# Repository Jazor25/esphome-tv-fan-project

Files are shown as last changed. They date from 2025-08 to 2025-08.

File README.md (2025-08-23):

# ESPHome TV Fan Project

This project demonstrates how to build a thermostat-controlled fan system for cooling gaming consoles, media players, or other hardware housed in enclosed cabinets. It includes a custom 3D-printed case that perfectly accommodates all components.

The system controls 2 fans independently based on temperature readings from 2 separate DHT22 sensors, and can easily be extended to support additional fans and sensors.

This solution integrates natively with Home Assistant via ESPHome while also operating autonomously, controlling fans based on cabinet temperature without external dependencies.

# Motivation

I wanted to create a clean TV/media setup in our living room with minimal visible devices on or around the TV cabinet. However, running hardware in closed cabinets without proper cooling leads to overheating issues, so I needed an effective cooling solution. I had previously built a similar system using an Arduino Uno three years ago, but it was no longer functioning reliably and lacked Home Assistant integration.

This project draws inspiration from the excellent work of [patrickcollins12 on GitHub](https://github.com/patrickcollins12/esphome-fan-controller). I developed my own version for several specific reasons:

* I only had 3-pin fans from a previous setup (no PWM control available)
* I wanted a transistor-controlled switching solution for reliable fan operation (PWM signals aren't always dependable for complete fan shutdown)
* My PlayStation 5 generates significant heat quickly, requiring fans to run at 100% capacity. Since I use ultra-quiet Noctua fans, speed reduction isn't necessary from a noise perspective. 

## Visuals
*(Additional images are available in the /img folder)*

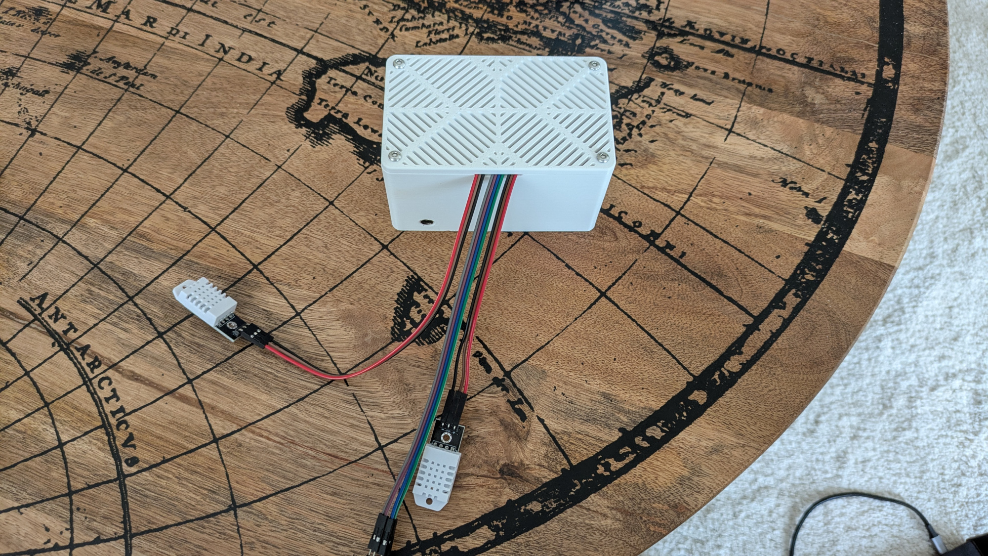
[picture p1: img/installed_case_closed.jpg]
Installed Case (Closed)

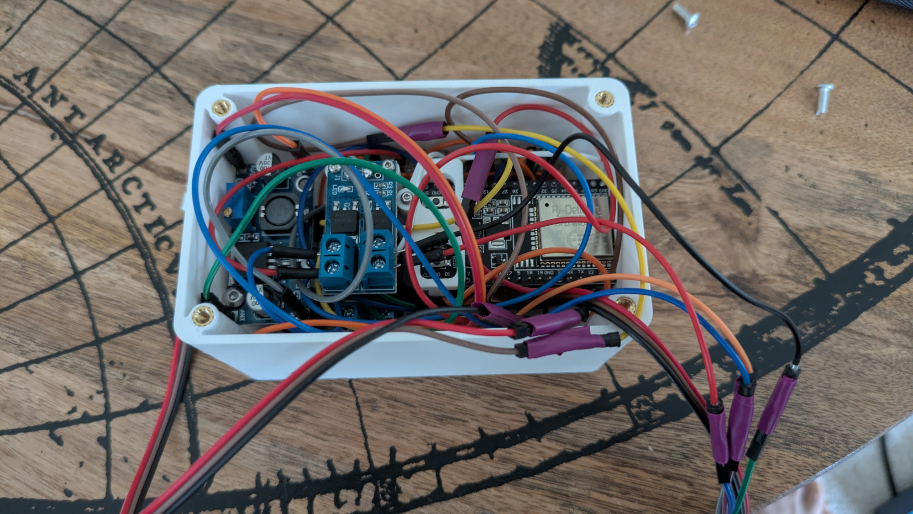
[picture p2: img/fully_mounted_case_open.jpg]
Mounted Case (Open)

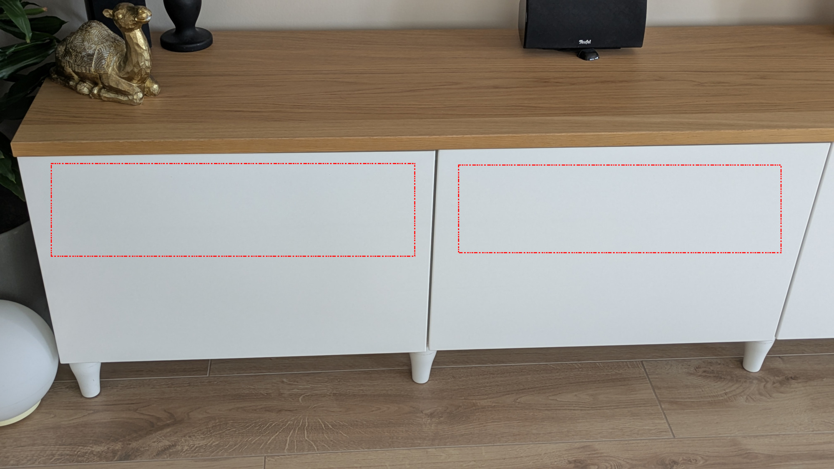
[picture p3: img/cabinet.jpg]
cabinet

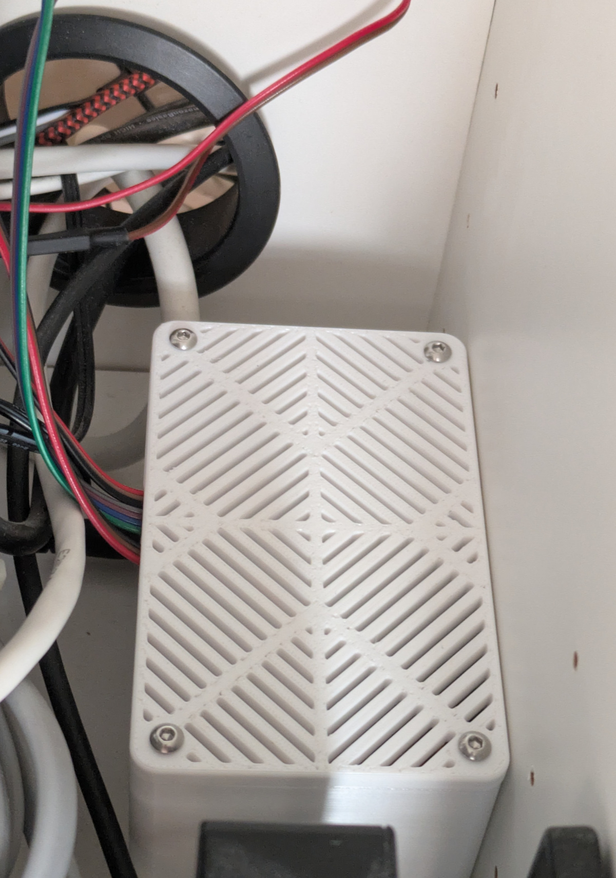
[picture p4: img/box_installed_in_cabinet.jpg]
Installed Case in cabinet

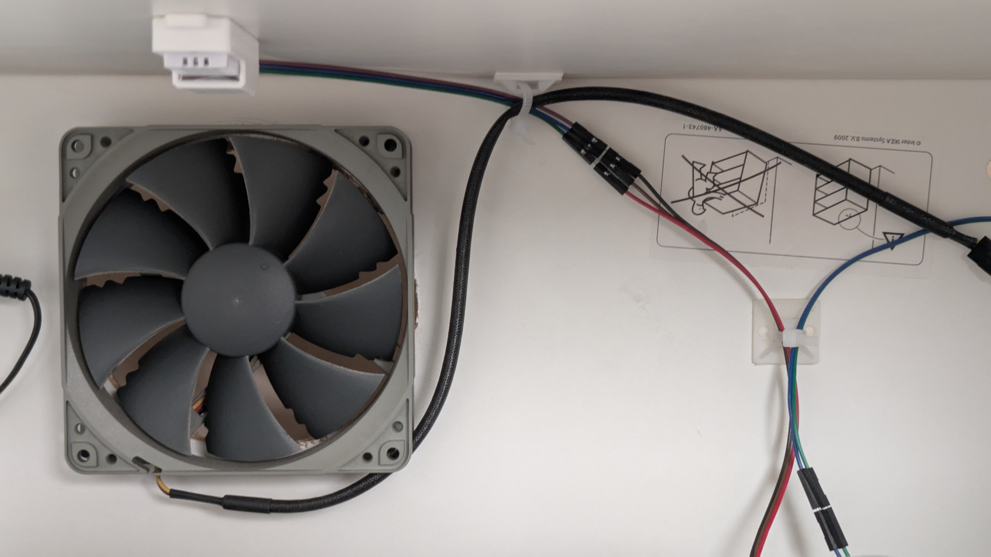
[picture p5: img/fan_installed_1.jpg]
Installed Fan 1

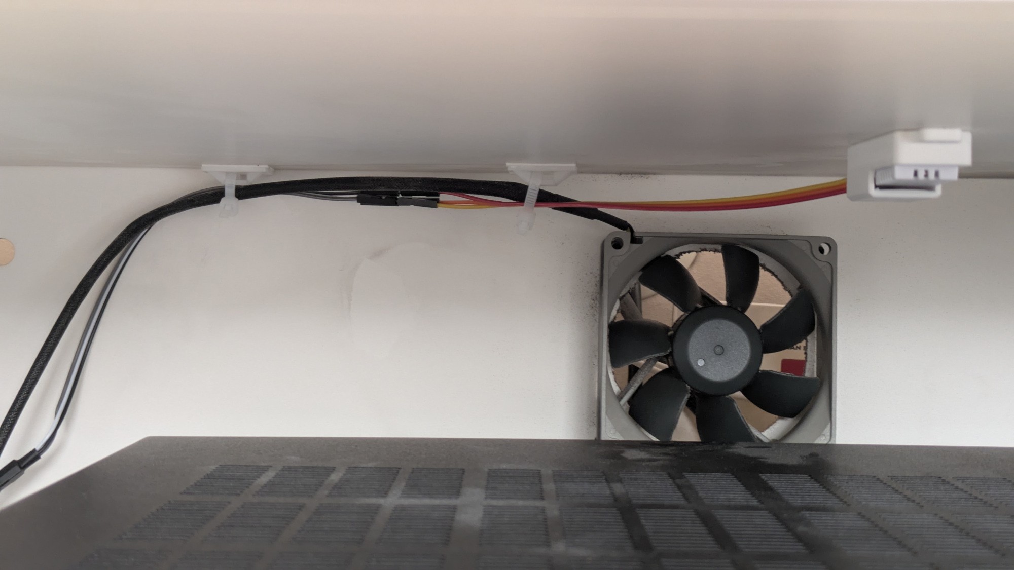
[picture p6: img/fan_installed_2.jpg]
Installed Fan 2

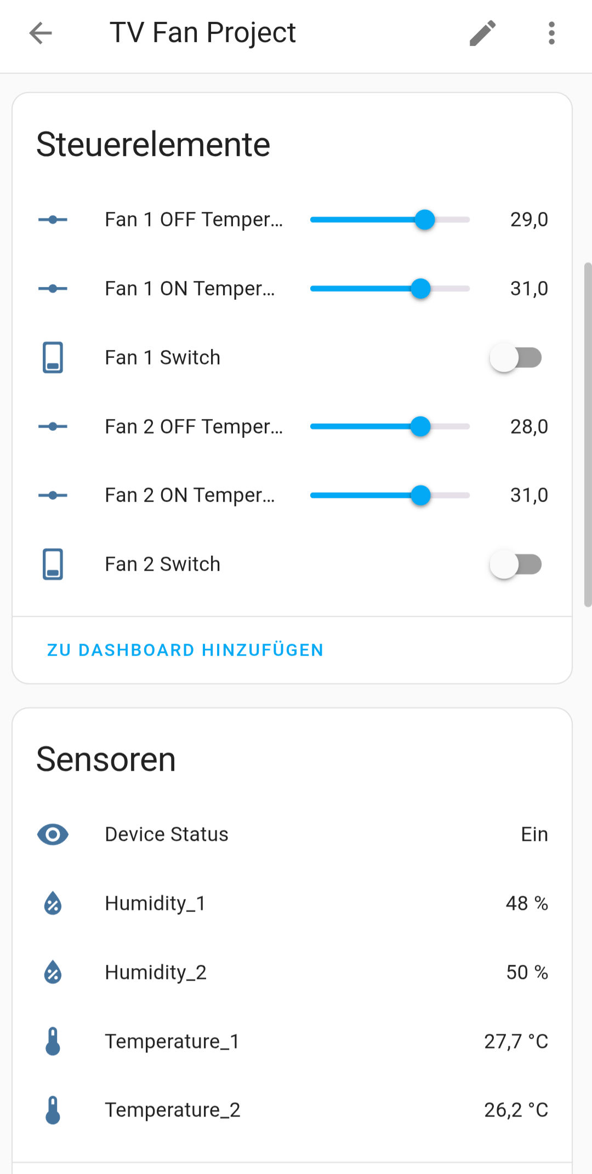
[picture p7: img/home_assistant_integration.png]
Home Assistant Integration

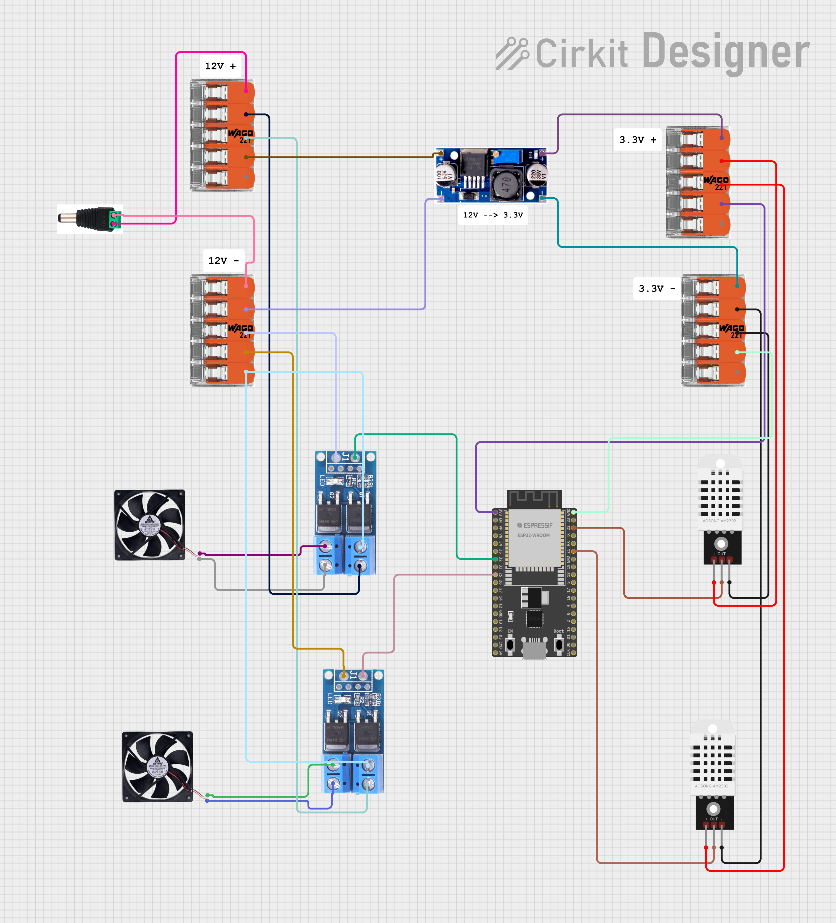
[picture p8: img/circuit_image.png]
Circuit Wiring


## Hardware Components

* ESP32 Development Board (Used: ESP32 V4 with CP2102, AZDelivery)
* 2× DC 5V-36V 400W FET Trigger Switch Boards
* 1× LM2596s Step-Down Voltage Regulator (24V/12V/5V/3V Buck Converter)
* 2x DHT22 Temperature/Humidity Sensors
* 2× 12V PC Fans (2-pin configuration)
* 12V 1-2A Power Supply
* 12V Male-to-Female Power Adapter
* Jumper cables
* 4× WAGO 221-415, COMPACT Splicing Connector, 5-pole (Optional, but fit well into the 3D-printed case) 

## Wiring & Pin Assignments

### GPIO Pin Usage
| GPIO Pin | Component | Description |
|---|---|---|
| GPIO22 | DHT22 #1  | Temperature/Humidity Sensor 1 |
| GPIO21 | DHT22 #2  | Temperature/Humidity Sensor 2 |
| GPIO32 | FET Board #1 | Fan 1 Control Signal |
| GPIO25 | FET Board #2 | Fan 2 Control Signal |

### Wiring Diagrams
- **[Complete Wiring Guide](docs/wiring_diagrams.md)** - Detailed connection tables, safety notes, and troubleshooting
- **[Visual Schematic](docs/detailed_schematic.txt)** - ASCII art diagram showing component connections
- **[Cable Assignments](img/cable_assignments.png)** - Physical cable reference

### Key Connections
- **Power**: 12V supply → LM2596s (configured to 3.3V) → ESP32 VIN
- **Sensors**: DHT22 data pins connected to GPIO22/21, powered by ESP32 3.3V
- **Fan Control**: GPIO32/25 → FET board signal pins
- **Ground**: Common ground connection for all components

## Features

- **Independent Control**: Each fan operates based on its dedicated temperature sensor
- **Configurable Thresholds**: Customize ON/OFF temperatures through Home Assistant
- **Hysteresis Control**: Prevents rapid fan cycling for stable operation
- **Web Interface**: Built-in web server for monitoring and control
- **Home Assistant Integration**: Full API integration with encryption support

## 3D Printed Case Hardware

* 5× Ruthex M3 Threaded Inserts
* 5× M3 Screws
* 7× Ruthex M2 Threaded Inserts  
* 7× M2 Screws

## Assembly Guidelines

* **Voltage Regulation**: The buck converter must be precisely adjusted to 3.3V to prevent damage to the ESP32 and connected modules. Connect 12V to the input pins, attach a multimeter (set to voltage mode) to the output pins, and carefully adjust the potentiometer with a screwdriver until the multimeter reads exactly 3.3V.

* **Compact Design**: The 3D case is designed for minimal size, which limits assembly flexibility. When soldering pins to components, ensure one of the FET boards has pins soldered "upside down" - otherwise, the case won't close properly. Refer to the images in the img folder if uncertain about component orientation. On the other hand, you avoid these issues if you use flexible soldering cables instead of jumper cables.

* **Safety Precautions**: Prevent bare 12V and 3.3V wire ends from touching each other, as this can cause immediate component failure. Use heat shrink tubing or electrical tape to insulate exposed connections, especially where jumper cables might accidentally contact each other and create short circuits. 

## License

This project is published under [CC BY-NC-SA 4.0](https://creativecommons.org/licenses/by-nc-sa/4.0/).

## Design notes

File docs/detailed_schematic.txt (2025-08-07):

```
ESP32 Fan Control System - Detailed Wiring Schematic
=====================================================

                    12V 1-2A Power Supply
                    ┌─────────────────────┐
                    │        +12V    GND  │
                    └──────────┬───────┬──┘
                               │       │
                    ┌──────────┴───────┴────────────────────────┐
                    │                                           │
                    │         Power Distribution                │
                    │                                           │
         ┌──────────┴─────┐    ┌─────────────────┐    ┌────────┴────────┐
         │                │    │                 │    │                 │
         │   LM2596s      │    │   FET Board #1  │    │   FET Board #2  │
         │ Buck Converter │    │   (GPIO32)      │    │   (GPIO25)      │
         │                │    │                 │    │                 │
         │ IN+  ←─ 12V    │    │ VCC ←─ 12V      │    │ VCC ←─ 12V      │
         │ IN-  ←─ GND    │    │ GND ←─ GND      │    │ GND ←─ GND      │
         │ OUT+ ──→ 3.3V  │    │ SIG ←─ ESP32    │    │ SIG ←─ ESP32    │
         │ OUT- ──→ GND   │    │ DC+ ──→ Fan #1+ │    │ DC+ ──→ Fan #2+ │
         └────────┬───────┘    │ DC- ──→ Fan #1- │    │ DC- ──→ Fan #2- │
                  │            └─────────┬───────┘    └─────────┬───────┘
                  │                      │                      │
                  │            ┌─────────┴───────┐    ┌─────────┴───────┐
                  │            │     Fan #1      │    │     Fan #2      │
                  │            │   (12V RPM)     │    │   (12V RPM)     │
                  │            │  Red(+) Black(-)│    │  Red(+) Black(-)│
                  │            └─────────────────┘    └─────────────────┘
                  │
            ┌─────┴─────────────────────────────────────────────────────┐
            │                    ESP32 V4                                │
            │                  (CP2102)                                  │
            │                                                            │
            │  VIN ←─ 3.3V (from LM2596s)                                │
            │  GND ←─ Common Ground                                      │
            │                                                            │
            │  GPIO22 ──→ DHT22 #1 Data   GPIO21 ──→ DHT22 #2 Data     │
            │  GPIO32 ──→ FET Board #1    GPIO25 ──→ FET Board #2       │
            │  3.3V   ──→ DHT22 Power (both sensors)                    │
            │                                                            │
            └──────────────┬─────────────────────┬─────────────────────┘
                           │                     │
                ┌──────────┴───────┐  ┌──────────┴───────┐
                │    DHT22 #1      │  │    DHT22 #2      │
                │ (Temperature &   │  │ (Temperature &   │
                │  Humidity)       │  │  Humidity)       │
                │                  │  │                  │
                │ 1. VCC ←─ 3.3V   │  │ 1. VCC ←─ 3.3V   │
                │ 2. Data ─→ GPIO22│  │ 2. Data ─→ GPIO21│
                │ 3. NC            │  │ 3. NC            │
                │ 4. GND ←─ GND    │  │ 4. GND ←─ GND    │
                │                  │  │                  │
                │ Note: Add 10kΩ   │  │ Note: Add 10kΩ   │
                │ pull-up resistor │  │ pull-up resistor │
                │ VCC to Data      │  │ VCC to Data      │
                └──────────────────┘  └──────────────────┘

Ground Distribution:
==================
                            Common Ground Bus
    ┌─────────────────────────────────────────────────────────────┐
    │                                                             │
    ├─ 12V Power Supply (-)                                       │
    ├─ LM2596s (IN-, OUT-)                                        │
    ├─ ESP32 (GND)                                                │
    ├─ DHT22 #1 (Pin 4)                                           │
    ├─ DHT22 #2 (Pin 4)                                           │
    ├─ FET Board #1 (GND)                                         │
    └─ FET Board #2 (GND)                                         │

Control Logic:
=============
Temperature Sensor 1 (GPIO22) → Controls → Fan 1 (GPIO32)
Temperature Sensor 2 (GPIO21) → Controls → Fan 2 (GPIO25)

Default Settings:
- Fan ON Temperature: 31.0°C
- Fan OFF Temperature: 29.0°C (Fan 1), 28.0°C (Fan 2)
- Check Interval: 10 seconds
- Sensor Update: 20 seconds

Signal Flow:
===========
DHT22 → ESP32 → Temperature Reading → Logic → GPIO Output → FET Board → Fan Control

Power Flow:
==========
12V Supply → LM2596s → 3.3V → ESP32
12V Supply → FET Boards → Fans (when triggered)
ESP32 3.3V → DHT22 Sensors
```

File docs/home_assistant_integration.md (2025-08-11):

# Adding ESPHome Fan Project to Home Assistant

## Method 1: ESPHome Add-on (Recommended)

### Prerequisites
- Home Assistant with Supervisor (Home Assistant OS or Supervised)
- ESPHome Add-on installed

### Step-by-Step Instructions

#### 1. Install ESPHome Add-on
1. Go to **Settings** → **Add-ons** → **Add-on Store**
2. Search for "ESPHome" 
3. Click **Install** on the official ESPHome add-on
4. Start the add-on and enable **Start on boot**

#### 2. Add Your Device
1. Open ESPHome add-on web UI
2. Click **+ NEW DEVICE**
3. Choose **Continue** 
4. Enter device details:
   - **Name**: `tv-fan-project`
   - **Device Type**: Choose ESP32
5. Skip the wireless credentials (we'll use existing config)

#### 3. Upload Your Configuration
1. In ESPHome dashboard, click **EDIT** on your new device
2. Replace the generated content with your `tv-fan-project.yaml` content
3. Create a `secrets.yaml` file with:
   ```yaml
   wifi_ssid: "Your_WiFi_Name"
   wifi_password: "Your_WiFi_Password"
   ```
4. Click **SAVE**

#### 4. Compile and Flash
1. Click **INSTALL** 
2. Choose **Wirelessly** (if device is already flashed) or **Plug into this computer**
3. Wait for compilation and upload

#### 5. Auto-Discovery in Home Assistant
- Once online, the device should appear in **Settings** → **Devices & Services**
- Look for "ESPHome" integration with your device
- Click **CONFIGURE** if prompted

## Method 2: Standalone ESPHome Installation

### If you're running ESPHome separately (not as HA add-on):

#### 1. Ensure API Configuration
Your configuration already has the API enabled:
```yaml
api:
  encryption:
    key: "YOUR_API_ENCRYPTION_KEY_HERE"
```

#### 2. Manual Integration
1. Go to **Settings** → **Devices & Services**
2. Click **+ ADD INTEGRATION**
3. Search for "ESPHome"
4. Enter your ESP32's IP address
5. Enter the encryption key from your ESPHome config

## Method 3: MQTT Integration (Alternative)

### If you prefer MQTT, add this to your ESPHome config:

```yaml
mqtt:
  broker: your_mqtt_broker_ip
  username: !secret mqtt_username
  password: !secret mqtt_password
  discovery: true
  discovery_retain: false
  topic_prefix: esphome/tv_fan_project
```

## Device Configuration for Better HA Integration

### Add Device Information
Add this to your ESPHome configuration for better device identification:

```yaml
esphome:
  name: tv-fan-project
  friendly_name: TV Fan Project
  comment: "Dual fan temperature control system"
  project:
    name: "custom.tv_fan_control"
    version: "1.0"

# Device information for Home Assistant
device_info:
  manufacturer: "Custom Build"
  model: "ESP32 Fan Controller"
  sw_version: "1.0"
```

## Expected Home Assistant Entities

After successful integration, you'll see these entities:

### 🌡️ **Climate Sensors**
- `sensor.tv_fan_project_temperature_1`
- `sensor.tv_fan_project_temperature_2` 
- `sensor.tv_fan_project_humidity_1`
- `sensor.tv_fan_project_humidity_2`

### 🔌 **Switches & Controls**
- `switch.tv_fan_project_fan_1_switch`
- `switch.tv_fan_project_fan_2_switch`
- `number.tv_fan_project_fan_on_temperature`
- `number.tv_fan_project_fan_on_temperature_2`
- `number.tv_fan_project_fan_off_temperature_1`
- `number.tv_fan_project_fan_off_temperature`

### 📊 **System Monitoring**
- `sensor.tv_fan_project_uptime`
- `sensor.tv_fan_project_wifi_signal`
- `text_sensor.tv_fan_project_fan_control_status`

### 🏠 **Device Status**
- `binary_sensor.tv_fan_project_status` (online/offline)

## Creating a Dashboard Card

### Example Lovelace Card Configuration:

```yaml
type: entities
title: TV Fan Control System
entities:
  - entity: text_sensor.tv_fan_project_fan_control_status
    name: System Status
  - type: divider
  - entity: sensor.tv_fan_project_temperature_1
    name: Temperature Zone 1
  - entity: sensor.tv_fan_project_temperature_2
    name: Temperature Zone 2
  - type: divider
  - entity: switch.tv_fan_project_fan_1_switch
    name: Fan 1 Manual Control
  - entity: switch.tv_fan_project_fan_2_switch
    name: Fan 2 Manual Control
  - type: divider
  - entity: number.tv_fan_project_fan_on_temperature
    name: Fan 1 ON Temp
  - entity: number.tv_fan_project_fan_off_temperature_1
    name: Fan 1 OFF Temp
  - entity: number.tv_fan_project_fan_on_temperature_2
    name: Fan 2 ON Temp
  - entity: number.tv_fan_project_fan_off_temperature
    name: Fan 2 OFF Temp
```

## Automation Example

### Create automations in Home Assistant:

```yaml
# Example: Notification when fan turns on
automation:
  - alias: "Fan System Alert"
    trigger:
      - platform: state
        entity_id: switch.tv_fan_project_fan_1_switch
        to: 'on'
      - platform: state
        entity_id: switch.tv_fan_project_fan_2_switch
        to: 'on'
    action:
      - service: notify.mobile_app_your_phone
        data:
          message: "Fan {{ trigger.entity_id.split('.')[1] }} activated due to high temperature"
```

## Troubleshooting

### Device Not Appearing
1. **Check Network**: Ensure ESP32 and HA are on same network
2. **Verify API**: Confirm API encryption key matches
3. **Check Logs**: Look in HA logs for connection errors
4. **Manual Add**: Try adding via IP address manually

### Connection Issues
1. **Firewall**: Ensure port 6053 is open for ESPHome API
2. **WiFi Signal**: Check `sensor.tv_fan_project_wifi_signal` strength
3. **Restart**: Reboot both ESP32 and Home Assistant

### Entity Names
- Entity names will be prefixed with your device name
- Use **Settings** → **Devices & Services** → **ESPHome** → your device to customize entity names

## Advanced Features

### Group Configuration
Create groups for easier management:

```yaml
# In configuration.yaml
group:
  fan_control_system:
    name: "TV Fan Control System"
    entities:
      - switch.tv_fan_project_fan_1_switch
      - switch.tv_fan_project_fan_2_switch
      - sensor.tv_fan_project_temperature_1
      - sensor.tv_fan_project_temperature_2
```

### Template Sensors
Create calculated sensors:

```yaml
# Average temperature sensor
template:
  - sensor:
      - name: "Average Room Temperature"
        unit_of_measurement: "°C"
        state: >
          {{ ((states('sensor.tv_fan_project_temperature_1') | float + 
               states('sensor.tv_fan_project_temperature_2') | float) / 2) | round(1) }}
```

Once you follow these steps, your ESPHome fan control system will be fully integrated into Home Assistant with all entities available for monitoring, control, and automation!

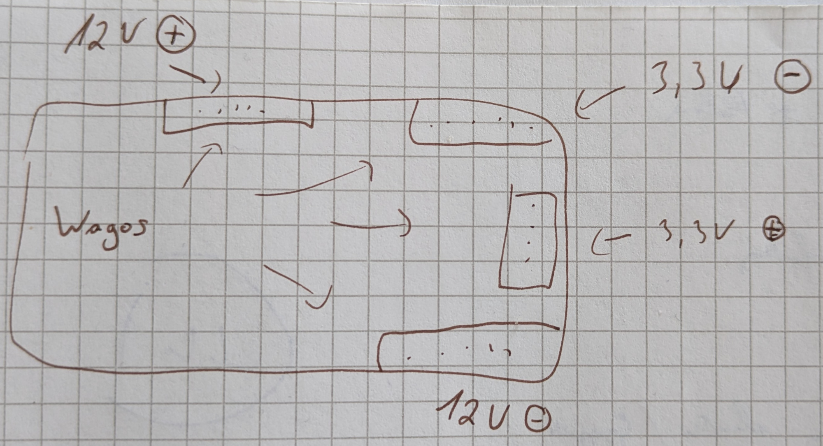
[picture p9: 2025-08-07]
img/wago_box_placement.jpg

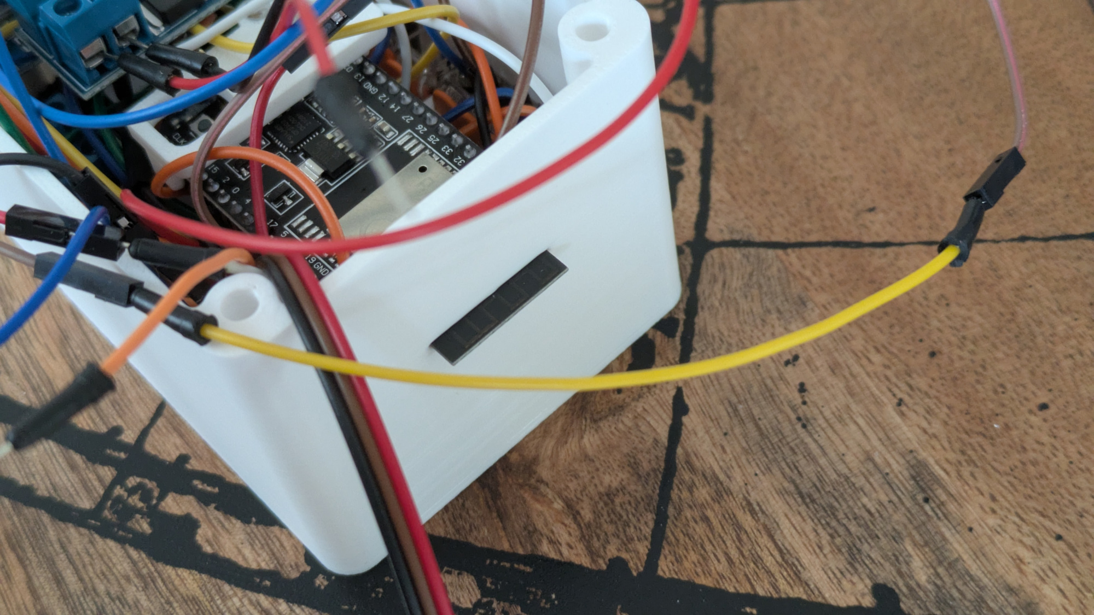
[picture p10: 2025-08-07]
img/esp32_antenna.jpg

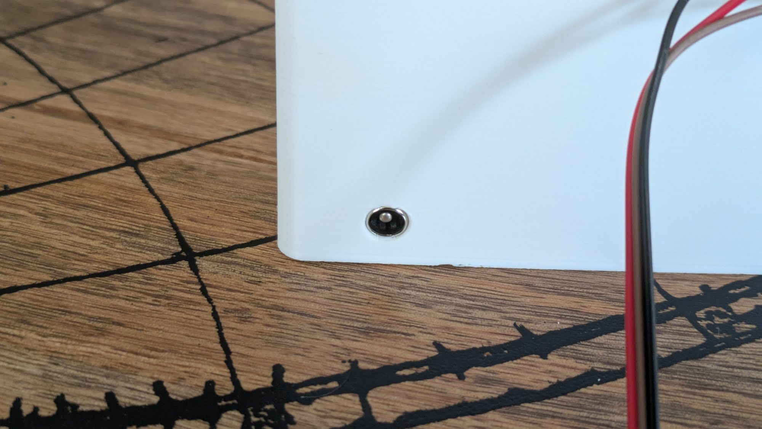
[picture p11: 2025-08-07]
img/12v_power_plug_female.jpg

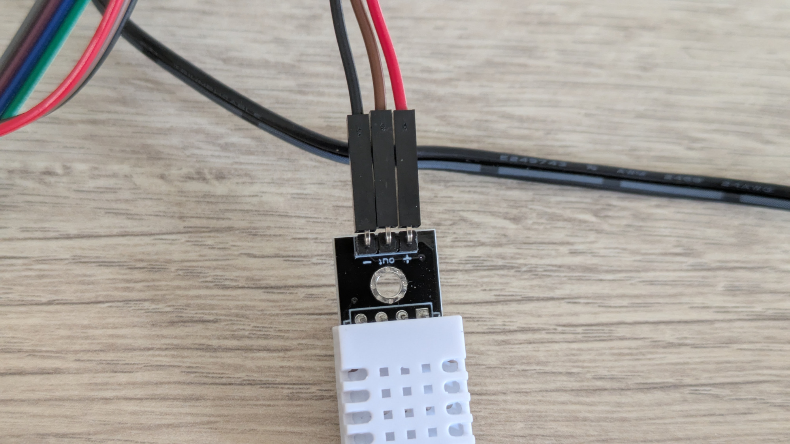
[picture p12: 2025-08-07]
img/DHT22_pin_assignment.jpg

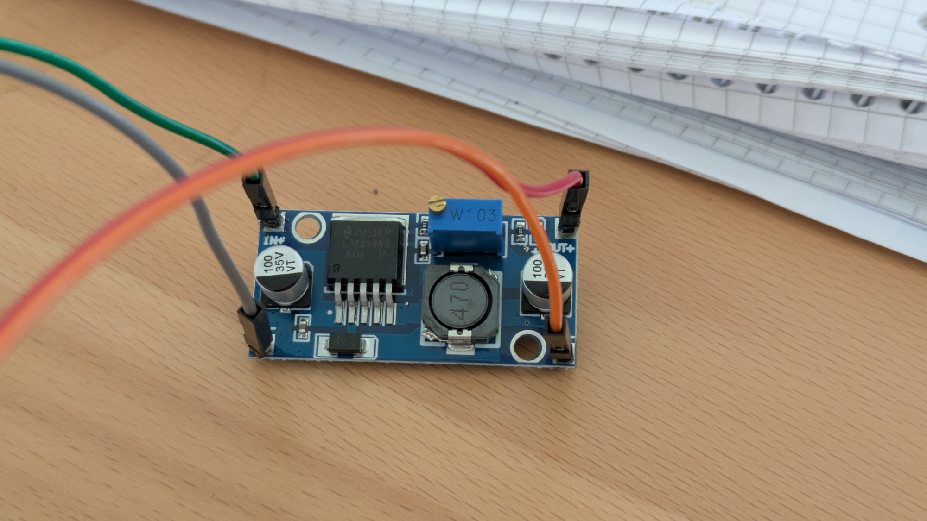
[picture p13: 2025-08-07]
img/LM2596s_buck_transformer.jpg

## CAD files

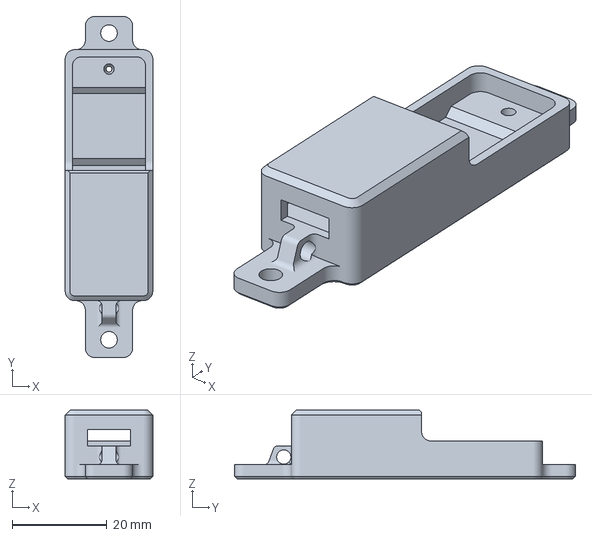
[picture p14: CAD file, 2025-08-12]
3d-print-files/DHT_Gehäuse.3mf
18.5 x 72.0 x 14.5 mm

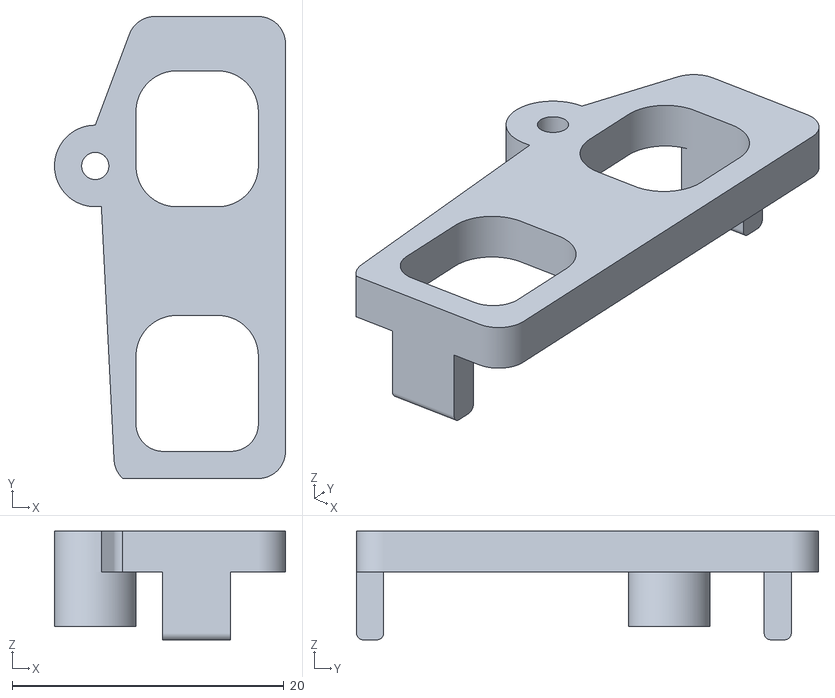
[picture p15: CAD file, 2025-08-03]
3d-print-files/box-esp32-holder.stl
17.0 x 34.0 x 8.00

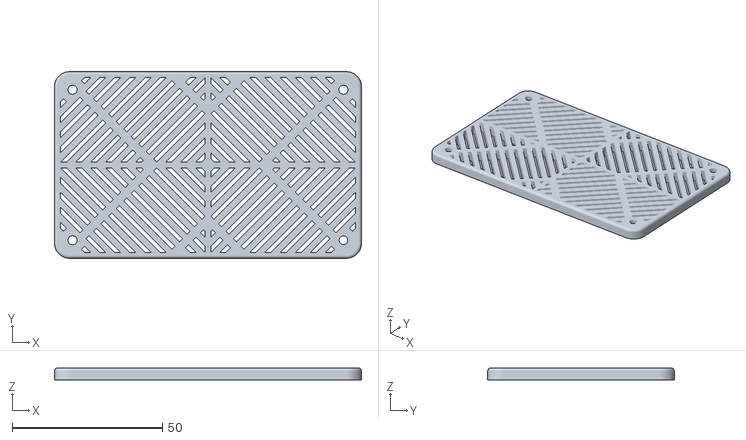
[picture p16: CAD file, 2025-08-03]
3d-print-files/box-cover-v2.stl
102.0 x 62.0 x 4.00

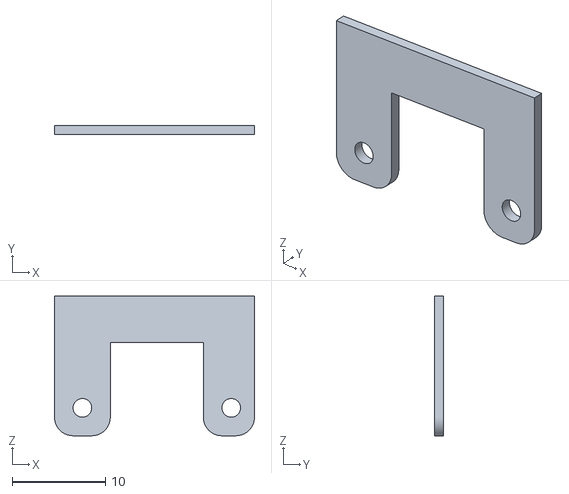
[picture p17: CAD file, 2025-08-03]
3d-print-files/box-powerplug-holder.stl
21.5 x 1.00 x 15.0

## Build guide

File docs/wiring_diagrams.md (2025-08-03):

# Wiring Diagrams - ESP Home Fan Project

## Pin Assignments Summary

### ESP32 GPIO Pin Usage
| GPIO Pin | Component | Description |
|---|---|---|
| GPIO22 | DHT22 #1  | Temperature/Humidity Sensor 1 |
| GPIO21 | DHT22 #2  | Temperature/Humidity Sensor 2 |
| GPIO32 | FET Board #1 | Fan 1 Control Signal |
| GPIO25 | FET Board #2 | Fan 2 Control Signal |
| 3.3V | DHT22 VCC | Power for both DHT22 sensors |
| GND | DHT22 GND | Ground for both DHT22 sensors |

## Main Wiring Diagram

```
                           ┌─────────────────┐
                           │     ESP32       │
                           │   (ESP32 V4)    │
                           │                 │
┌─────────────┐           │  GPIO22  ────── │ ──── DHT22 #1 Data
│             │           │  GPIO21  ────── │ ──── DHT22 #2 Data
│  12V Power  │           │  GPIO32  ────── │ ──── FET Board #1 Signal
│   Supply    │           │  GPIO25  ────── │ ──── FET Board #2 Signal
│             │           │                 │
│   +12V ─────┼───────────│  VIN     ────── │ ──── 12V --> 3.3V Input (via Buck Converter)
│    GND ─────┼───────────│  GND     ────── │ ──── Common Ground
└─────────────┘           │  3.3V    ────── │ ──── DHT22 VCC (both sensors)
                           └─────────────────┘
                                    │
                                    │
                           ┌─────────────────┐
                           │  LM2596s Buck   │
                           │   Converter     │
                           │   (24V→5V/3V)   │
                           │                 │
                           │  IN+  ←─ 12V    │
                           │  IN-  ←─ GND    │
                           │  OUT+ ──→ 3.3V  │ ──── To ESP32 VIN
                           │  OUT- ──→ GND   │ ──── Common Ground
                           └─────────────────┘
```

## DHT22 Sensors Wiring

```
DHT22 Sensor #1                    DHT22 Sensor #2
┌─────────────┐                    ┌─────────────┐
│      ┌─┐    │                    │      ┌─┐    │
│   1 ─┤ |    │                    │   1 ─┤ |    │
│   2 ─┤ ├─ 3 │                    │   2 ─┤ ├─ 3 │
│      └─┘    │                    │      └─┘    │
└─────────────┘                    └─────────────┘
Pin 1: VCC (3.3V)                  Pin 1: VCC (3.3V)
Pin 2: Data → GPIO22               Pin 2: Data → GPIO21
Pin 3: GND                         Pin 3: GND

```

## FET Switch Board Connections

```
FET Board #1                       FET Board #2
┌─────────────────┐                ┌─────────────────┐
│  DC+ ←─ Fan 1 + │                │  DC+ ←─ Fan 2 + │
│  DC- ←─ Fan 1 - │                │  DC- ←─ Fan 2 - │
│                 │                │                 │
│  VCC ←─ 12V     │                │  VCC ←─ 12V     │
│  GND ←─ GND     │                │  GND ←─ GND     │
│  SIG ←─ GPIO32  │                │  SIG ←─ GPIO25  │
└─────────────────┘                └─────────────────┘
       │                                  │
       │                                  │
┌─────────────┐                    ┌─────────────┐
│   Fan #1    │                    │   Fan #2    │
│  (12V RPM)  │                    │  (12V RPM)  │
│             │                    │             │
│    + Red    │                    │    + Red    │
│    - Black  │                    │    - Black  │
└─────────────┘                    └─────────────┘
```

## Power Distribution

```
┌─────────────┐
│  12V 1-2A   │
│ Power Supply│
│             │
│    +12V ────┼─┬─── LM2596s Input
│     GND ────┼─┼─── FET Board #1 VCC
└─────────────┘ │    FET Board #2 VCC
                │    Fan #1 Power (via FET)
                │    Fan #2 Power (via FET)
                │
                └─── Common Ground (All Components)

LM2596s Output:
3.3V ────── ESP32 VIN
GND ───── Common Ground
```

## Complete Connection Table

| Component | Pin/Terminal | Connects To | Wire Color Suggestion |
|---|---|---|---|
| **ESP32** | | | |
| | VIN | LM2596s OUT+ | Red |
| | GND | Common Ground | Black |
| | 3.3V | DHT22 #1 & #2 VCC | Red |
| | GPIO22 | DHT22 #1 Data | Yellow |
| | GPIO21 | DHT22 #2 Data | Orange |
| | GPIO32 | FET Board #1 SIG | Green |
| | GPIO25 | FET Board #2 SIG | Blue |
| **DHT22 #1** | | | |
| | VCC | ESP32 3.3V | Red |
| | Data | ESP32 GPIO22 | Yellow |
| | GND | Common Ground | Black |
| **DHT22 #2** | | | |
| | VCC | ESP32 3.3V | Red |
| | Data | ESP32 GPIO21 | Orange |
| | GND | Common Ground | Black |
| **FET Board #1** | | | |
| | VCC | 12V Supply + | Red |
| | GND | Common Ground | Black |
| | SIG | ESP32 GPIO32 | Green |
| | DC+ | Fan #1 + | Red |
| | DC- | Fan #1 - | Black |
| **FET Board #2** | | | |
| | VCC | 12V Supply + | Red |
| | GND | Common Ground | Black |
| | SIG | ESP32 GPIO25 | Blue |
| | DC+ | Fan #2 + | Red |
| | DC- | Fan #2 - | Black |
| **LM2596s** | | | |
| | IN+ | 12V Supply + | Red |
| | IN- | Common Ground | Black |
| | OUT+ | ESP32 VIN | Red |
| | OUT- | Common Ground | Black |

## Safety Notes

1. **Power Supply Ratings**: Ensure 12V supply can handle total current draw (ESP32 + 2 fans)
2. **Heat Dissipation**: FET boards may generate heat under load - ensure adequate ventilation
3. **Voltage Regulation**: Set LM2596s output to 3.3V for ESP32 VIN pin
4. **Common Ground**: All components must share common ground connection
5. **Wire Gauge**: Use appropriate wire gauge for 12V fan current (typically 18-20 AWG)

## Testing Procedure

1. Power on system without fans connected
2. Verify ESP32 boots and connects to WiFi
3. Check DHT22 sensor readings in Home Assistant
4. Test FET board switching with manual override
5. Connect fans and test temperature-based control
6. Monitor for proper on/off hysteresis behavior

## Troubleshooting

| Issue | Check |
|---|---|
| DHT22 not reading | wiring, power |
| Fan not switching | FET board power, signal connection |
| ESP32 not booting | Power supply voltage, current capacity |
| Erratic behavior | Common ground, power supply stability |

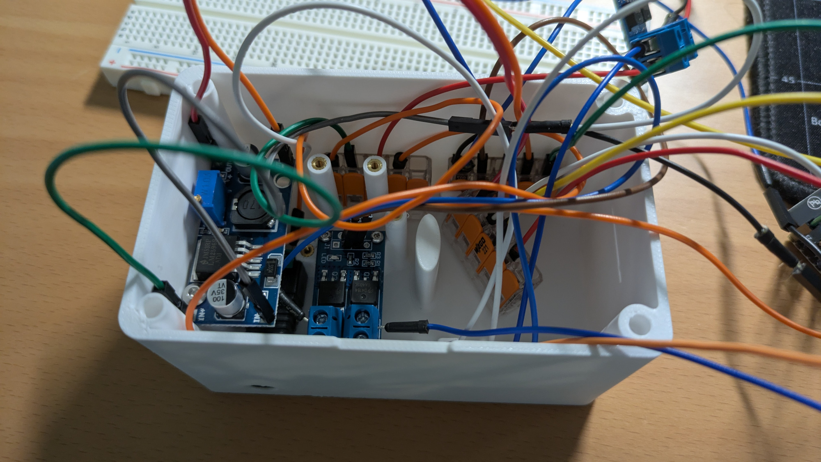
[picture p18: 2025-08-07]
img/partially_installed_case_open.jpg

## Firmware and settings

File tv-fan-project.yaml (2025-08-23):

esphome:
  name: tv-fan-project
  friendly_name: TV Fan Project
  comment: "Dual fan temperature control system with independent DHT22 sensors"
  project:
    name: "custom.tv_fan_control"
    version: "1.0"
  on_boot:
    priority: -100
    then:
      - text_sensor.template.publish:
          id: device_status
          state: "on"

esp32:
  board: esp32dev
  framework:
    type: esp-idf


# Enable logging
logger:

# Enable Home Assistant API
api:
  encryption:
    key: !secret api_encryption_key

ota:
  - platform: esphome
    password: !secret ota_password

wifi:
  ssid: !secret wifi_ssid
  password: !secret wifi_password

  # Enable fallback hotspot (captive portal) in case wifi connection fails
  ap:
    ssid: "Tv-Fan-Project Fallback Hotspot"
    password: !secret ap_wifi_password

captive_portal:

#web_server:

sensor:
  - platform: dht
    pin: GPIO22
    model: DHT22
    temperature:
      name: "Temperature_1"
      id: room_temp_1
    humidity:
      name: "Humidity_1"
    update_interval: 20s

  - platform: dht
    pin: GPIO21
    model: DHT22
    temperature:
      name: "Temperature_2"
      id: room_temp_2
    humidity:
      name: "Humidity_2"
    update_interval: 20s

  # System monitoring sensors
  - platform: uptime
    name: "Uptime"
    update_interval: 60s

  - platform: wifi_signal
    name: "WiFi Signal"
    update_interval: 60s

# Text sensors for system status
text_sensor:
  - platform: template
    id: device_status
    name: "Device Status"
    update_interval: never

  - platform: wifi_info
    ip_address:
      name: "IP Address"


switch:
  - platform: gpio
    pin: GPIO32               # The GPIO pin to control the fan relay
    id: fan_switch_1
    name: "Fan 1 Switch"
    inverted: false
    on_turn_on:
      - logger.log:
          format: "Fan 1 relay activated (GPIO32 HIGH)"
          level: INFO
    on_turn_off:
      - logger.log:
          format: "Fan 1 relay deactivated (GPIO32 LOW)"
          level: INFO

  - platform: gpio
    pin: GPIO25               # The GPIO pin to control the fan relay
    id: fan_switch_2
    name: "Fan 2 Switch"
    inverted: false
    on_turn_on:
      - logger.log:
          format: "Fan 2 relay activated (GPIO25 HIGH)"
          level: INFO
    on_turn_off:
      - logger.log:
          format: "Fan 2 relay deactivated (GPIO25 LOW)"
          level: INFO

number:
  - platform: template
    name: "Fan 1 ON Temperature"
    id: fan_on_temp_1
    min_value: 10
    max_value: 40
    step: 0.5
    initial_value: 31.0  # old default: 32
    set_action:
      then:
        - logger.log:
            format: "Fan 1 ON Temp set to %.1f"
            args: [x]       # x is the value in set_action

  - platform: template
    name: "Fan 1 OFF Temperature"
    id: fan_off_temp_1
    min_value: 5
    max_value: 38
    step: 0.5
    initial_value: 28.0  # old default: 28
    set_action:
      then:
        - logger.log:
            format: "Fan 1 OFF Temp set to %.1f"
            args: [x]

  - platform: template
    name: "Fan 2 ON Temperature"
    id: fan_on_temp_2
    min_value: 10
    max_value: 40
    step: 0.5
    initial_value: 31.0 # old default: 32
    set_action:
      then:
        - logger.log:
            format: "Fan 2 ON Temp set to %.1f"
            args: [x]       # x is the value in set_action

  - platform: template
    name: "Fan 2 OFF Temperature"
    id: fan_off_temp_2
    min_value: 5
    max_value: 38
    step: 0.5
    initial_value: 28.0 # old default: 28
    set_action:
      then:
        - logger.log:
            format: "Fan 2 OFF Temp set to %.1f"
            args: [x]
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

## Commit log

2025-07-28 initial working configuration of the esphome example with DHT-11 attached to it
2025-07-28 added some example code to use dtt22, transistor on/off code, switch case statements for temperature on off control. will not work like that yet
    [tv-fan-project.yaml]
2025-07-31 changed gpio of fan1 transistor switch
2025-07-31 perplexity fixed some issues, not it works with some default values and one fan
    [tv-fan-project.yaml]
2025-08-01 set default temperatures as comments that prooved well for old fan project
2025-08-02 some log corrections, put should default fan temperatures as comments
    [tv-fan-project.yaml]
2025-08-02 switched DHT Pins because outside order of cables was reversed
    [tv-fan-project.yaml]
2025-08-02 changed temperatures for productive use
2025-08-02 copilot created wiring diagrams. img added with wiring color assignments. does not switch fan states in case no change is necessary. Improved loggings incl. debug
2025-08-02 fan on off names were incomplete
2025-08-03 remove crappy device status temperature infos. Added simple device status ON template for sensor status
2025-08-03 added 3d print files, slightly adapted readme
    [Box ESP32-Fixierer_v2.stl, Box Powerplug-Fierer.stl, Box_Deckel_v2.stl]
2025-08-03 wiring diagram corrections
2025-08-03 on_boot was broken somehow
    [tv-fan-project.yaml]
2025-08-07 added secret sample, moved ap secret
2025-08-07 small wiring diagram fixes
2025-08-11 renamed 3d print files
    [box-cover-v2.stl, box-esp32-holder.stl, box-powerplug-holder.stl]
2025-08-12 added dht11 3d file
    [DHT_Gehäuse.3mf]
2025-08-20 added circuit diagram
2025-08-20 updated circuit diagram
2025-08-20 modified circuit diagram
